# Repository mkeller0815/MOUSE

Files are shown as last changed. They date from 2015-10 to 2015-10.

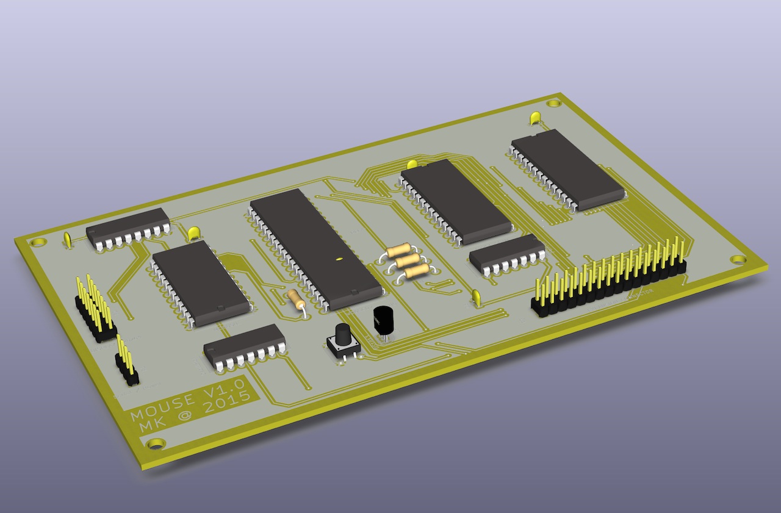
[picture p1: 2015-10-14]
PCB/MOUSE_1-3D.jpg

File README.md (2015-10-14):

# MOUSE

MOUSE (Mario's Own Unique SingleBoard Engine) is minimal 8bit computer system based on the W65C02 microprocessor.

## Files

 * Documentation - documentation, datasheets, images etc.
 * LICENSE - filed under MIT license
 * PCB - KiCad files for pcb of the computer
 * README.md - this file
 * Source - all the sources for the I/O system, minimal OS and some software

Each subdirectory has its own README file with further information about the content

## Concept

This is a single board computer with a minimal chipcount. It is powerd by a USB2Serial Aadapter that also provides 
access to the computer via serial connection. Any TTL serial-adapter that has RX/TX lines as well as +5V and GND 
is suitable.

The computer has 32k SRAM and 8k ROM. There are also 2 extension headers for additional hardware

## Hardware

 * W65C02 CPU 
 * 32k SRAM
 * 8k EEPROM
 * M6850 ACIA (serial interface)
 * DS1813 reset circuit

## Software 

 * DRIVER - provideing highlevel access to peripherals
 * MIOS - Minimal Input/Output System 
 * M-OS - MOUSE OS 
 * Programms - third party software adapted to MOUSE

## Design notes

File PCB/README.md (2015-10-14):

# MOUSE - PCB

This is the pcb sectoion of the project. It provides the schematic as well as the pcb layout and all the files that are needed to create or order a pcb.

## IMPORTANT NOTE

Currently this part is under development and will change in the near future. 

There are two known problems at the moment that make the expension ports less usefull. In the address decoding there are two lines swapped.

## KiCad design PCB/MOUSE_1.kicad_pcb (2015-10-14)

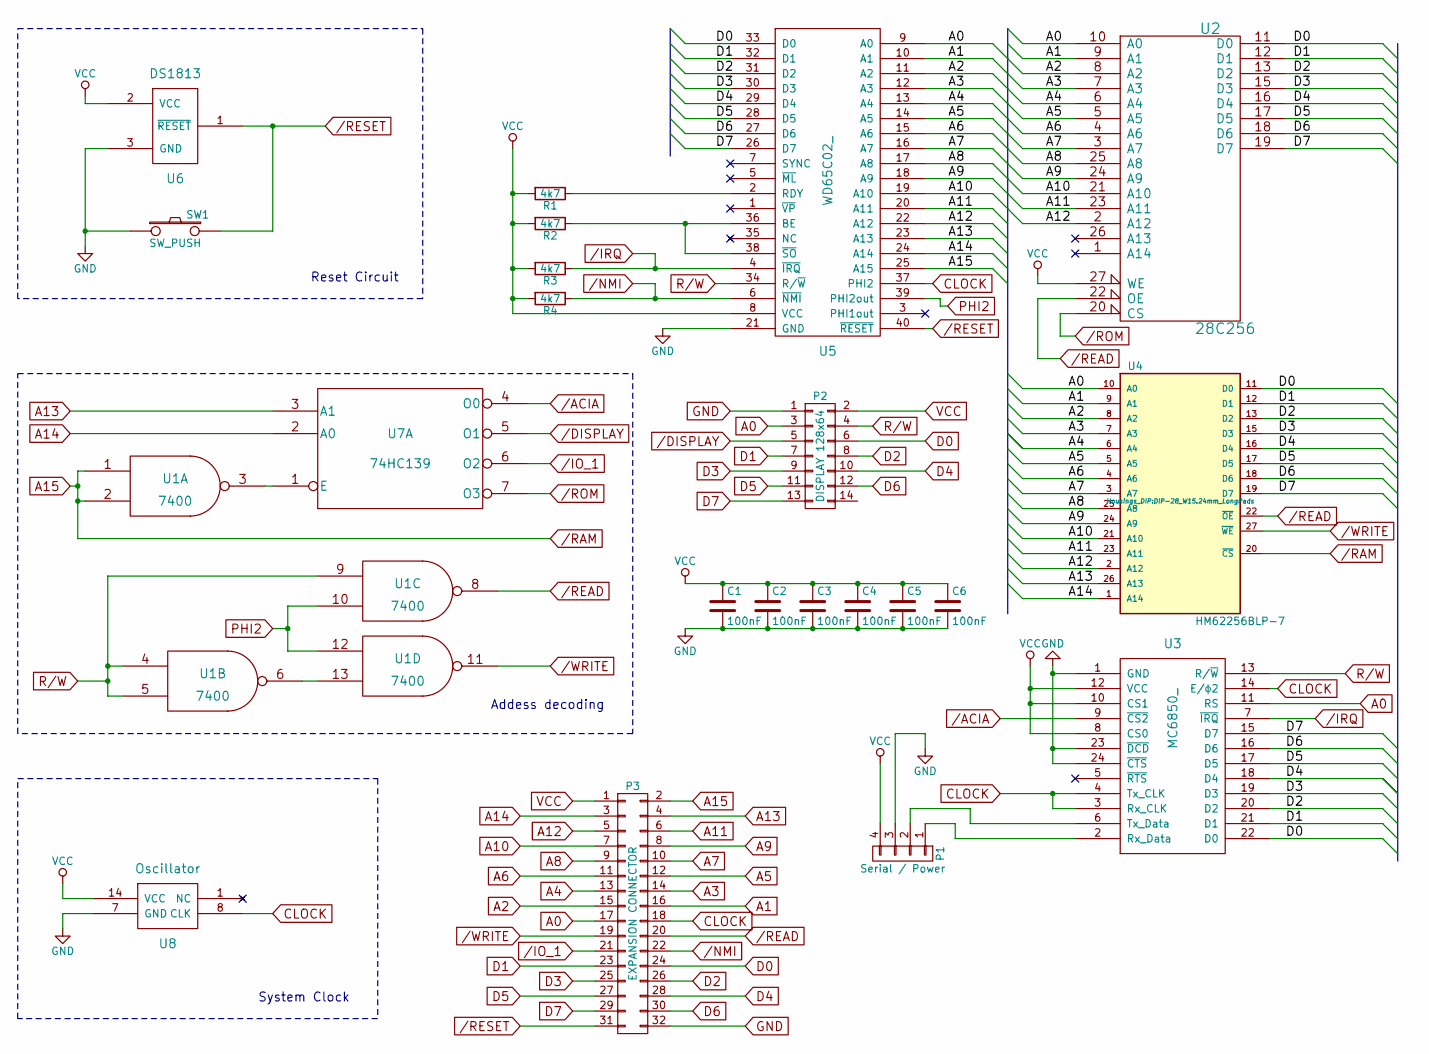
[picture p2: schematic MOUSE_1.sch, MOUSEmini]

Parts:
C1, C2, C3, C4, C5, C6: 100nF; C_Disc_D3_P2.5
P1: Serial / Power; Pin_Header_Straight_1x04
P2: DISPLAY 128x64; Pin_Header_Straight_2x07
P3: EXPANSION CONNECTOR; Pin_Header_Straight_2x16
R1, R2, R3, R4: 4k7; Resistor_Horizontal_RM10mm
SW1: SW_PUSH; SW_PUSH_SMALL
U1: 7400; DIP-14_W7.62mm_LongPads
U2: 28C256; DIP-28_W15.24mm_LongPads
U3: MC6850_; DIP-24_W15.24mm_LongPads
U4: HM62256BLP-7; DIP-28_W15.24mm_LongPads
U5: WD65C02_; DIP-40_W15.24mm_LongPads
U6: DS1813; TO-92_Inline_Narrow_Oval
U7: 74HC139; DIP-16_W7.62mm_LongPads
U8: Oscillator; DIP-14_W7.62mm_LongPads

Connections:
/ACIA: U3.9 (~CS2), U7.4 (O0)
/DISPLAY: P2.5, U7.5 (O1)
/IO_1: P3.21, U7.6 (O2)
/IRQ: R3.1, U3.7 (~IRQ), U5.4 (~IRQ)
/NMI: P3.22, R4.1, U5.6 (~NMI)
/READ: P3.20, U1.8, U2.22 (OE), U4.22 (~OE)
/RESET: P3.31, SW1.2, U5.40 (~RESET), U6.1 (~RESET)
/ROM: U2.20 (CS), U7.7 (O3)
/WRITE: P3.19, U1.11, U4.27 (~WE)
A0: P2.3, P3.17, U2.10 (A0), U3.11 (RS), U4.10 (A0), U5.9 (A0)
A1: P3.16, U2.9 (A1), U4.9 (A1), U5.10 (A1)
A2: P3.15, U2.8 (A2), U4.8 (A2), U5.11 (A2)
A3: P3.14, U2.7 (A3), U4.7 (A3), U5.12 (A3)
A4: P3.13, U2.6 (A4), U4.6 (A4), U5.13 (A4)
A5: P3.12, U2.5 (A5), U4.5 (A5), U5.14 (A5)
A6: P3.11, U2.4 (A6), U4.4 (A6), U5.15 (A6)
A7: P3.10, U2.3 (A7), U4.3 (A7), U5.16 (A7)
A8: P3.9, U2.25 (A8), U4.25 (A8), U5.17 (A8)
A9: P3.8, U2.24 (A9), U4.24 (A9), U5.18 (A9)
A10: P3.7, U2.21 (A10), U4.21 (A10), U5.19 (A10)
A11: P3.6, U2.23 (A11), U4.23 (A11), U5.20 (A11)
A12: P3.5, U2.2 (A12), U4.2 (A12), U5.22 (A12)
A13: P3.4, U4.26 (A13), U5.23 (A13), U7.3 (A1)
A14: P3.3, U4.1 (A14), U5.24 (A14), U7.2 (A0)
A15: P3.2, U1.1, U1.2, U4.20 (~CS), U5.25 (A15)
CLOCK: P3.18, U3.3 (Rx_CLK), U3.4 (Tx_CLK), U3.14 (E/ϕ2), U5.37 (PHI2), U8.8 (CLK)
D0: P2.6, P3.24, U2.11 (D0), U3.22 (D0), U4.11 (D0), U5.33 (D0)
D1: P2.7, P3.23, U2.12 (D1), U3.21 (D1), U4.12 (D1), U5.32 (D1)
D2: P2.8, P3.26, U2.13 (D2), U3.20 (D2), U4.13 (D2), U5.31 (D2)
D3: P2.9, P3.25, U2.15 (D3), U3.19 (D3), U4.15 (D3), U5.30 (D3)
D4: P2.10, P3.28, U2.16 (D4), U3.18 (D4), U4.16 (D4), U5.29 (D4)
D5: P2.11, P3.27, U2.17 (D5), U3.17 (D5), U4.17 (D5), U5.28 (D5)
D6: P2.12, P3.30, U2.18 (D6), U3.16 (D6), U4.18 (D6), U5.27 (D6)
D7: P2.13, P3.29, U2.19 (D7), U3.15 (D7), U4.19 (D7), U5.26 (D7)
GND: C1.2, C2.2, C3.2, C4.2, C5.2, C6.2, P1.3, P2.1, P3.32, SW1.1, U1.7 (GND), U2.14 (GND), U3.1 (GND), U3.23 (~DCD), U3.24 (~CTS), U4.14 (GND), U5.21 (GND), U6.3 (GND), U7.8 (GND), U8.7 (GND)
unnamed: P1.1, U3.2 (Rx_Data)
unnamed: P1.2, U3.6 (Tx_Data)
unnamed: R1.1, U5.2 (RDY)
unnamed: R2.1, U5.36 (BE), U5.38 (~SO)
unnamed: U1.3, U7.1 (E)
unnamed: U1.6, U1.13
PHI2: U1.10, U1.12, U5.39 (PHI2out)
R/W: P2.4, U1.4, U1.5, U1.9, U3.13 (R/~W), U5.34 (R/~W)
VCC: C1.1, C2.1, C3.1, C4.1, C5.1, C6.1, P1.4, P2.2, P3.1, R1.2, R2.2, R3.2, R4.2, U1.14 (VCC), U2.27 (WE), U2.28 (VCC), U3.8 (CS0), U3.10 (CS1), U3.12 (VCC), U4.28 (VCC), U5.8 (VCC), U6.2 (VCC), U7.16 (VCC), U8.14 (VCC)

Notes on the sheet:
Reset Circuit
Addess decoding
System Clock

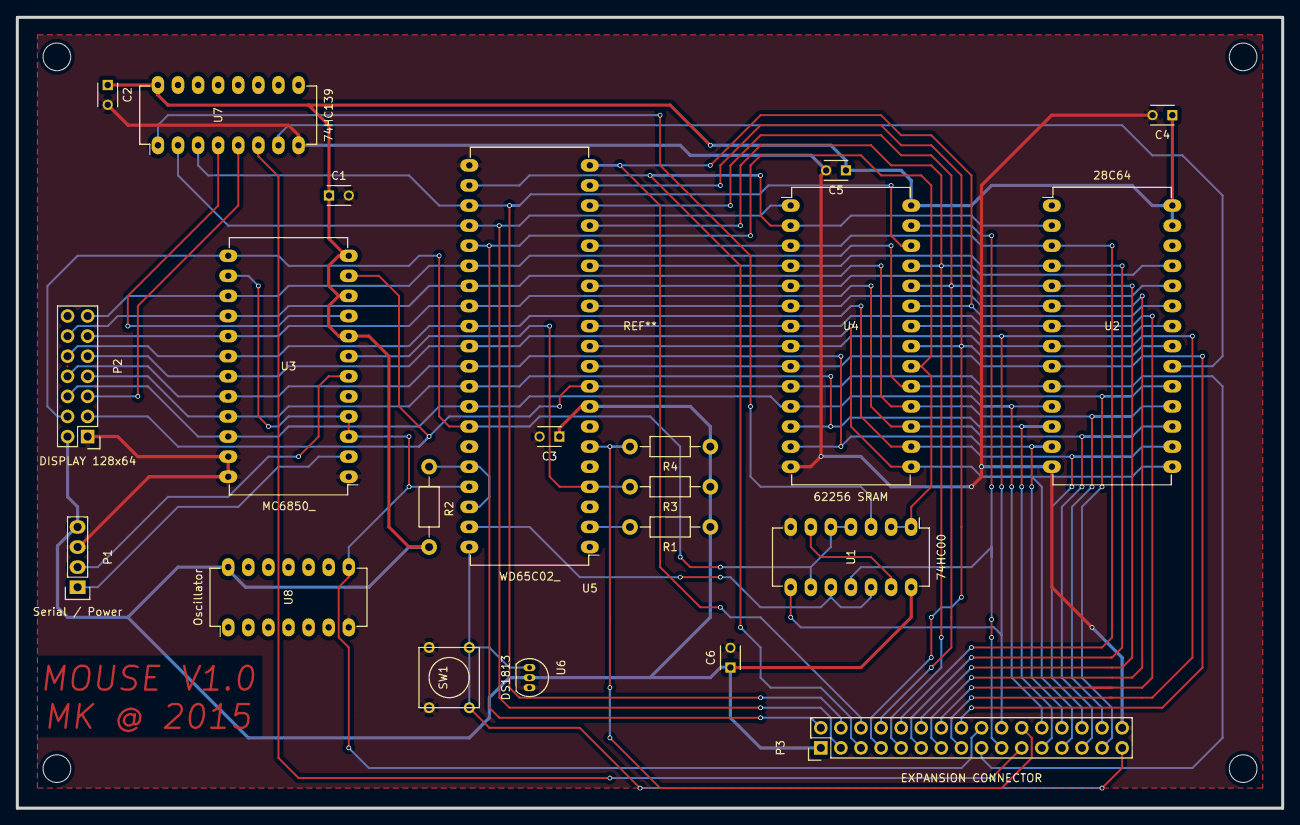
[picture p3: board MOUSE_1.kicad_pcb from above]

Board: 2 copper layers, 160.0 x 100.0 mm, 22 parts (0 on the bottom side), 44 nets.

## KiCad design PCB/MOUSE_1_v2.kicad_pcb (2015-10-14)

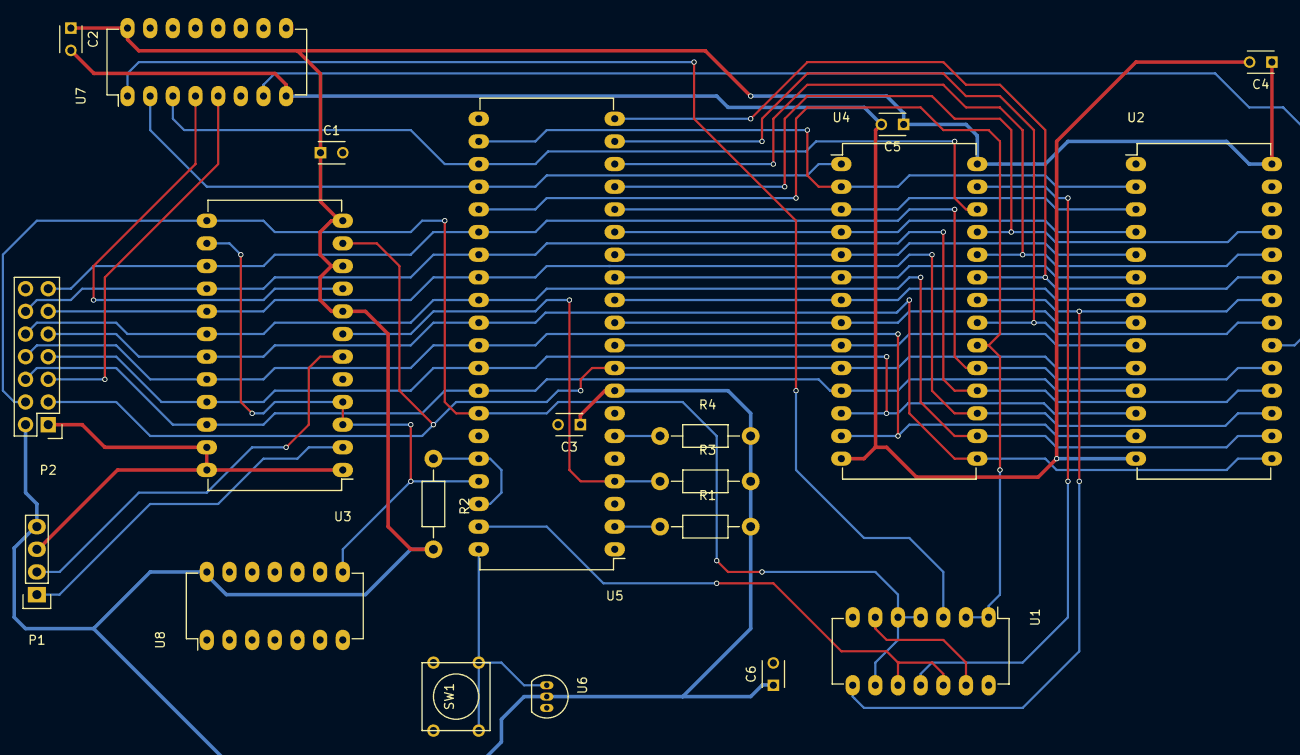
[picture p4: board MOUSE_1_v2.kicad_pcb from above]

Board: 2 copper layers, 21 parts (0 on the bottom side), 43 nets.

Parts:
C1, C2, C3, C4, C5, C6: 100nF; C_Disc_D3_P2.5
P1: Serial / Power; Pin_Header_Straight_1x04
P2: DISPLAY 128x64; Pin_Header_Straight_2x07
R1, R2, R3, R4: 4k7; Resistor_Horizontal_RM10mm
SW1: SW_PUSH; SW_PUSH_SMALL
U1: 7400; DIP-14_W7.62mm_LongPads
U2: 28C256; DIP-28_W15.24mm_LongPads
U3: MC6850_; DIP-24_W15.24mm_LongPads
U4: HM62256BLP-7; DIP-28_W15.24mm_LongPads
U5: WD65C02_; DIP-40_W15.24mm_LongPads
U6: DS1813; TO-92_Inline_Narrow_Oval
U7: 74HC139; DIP-16_W7.62mm_LongPads
U8: Oscillator; DIP-14_W7.62mm_LongPads

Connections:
/A1: U2.9, U4.9, U5.10
/A2: U2.8, U4.8, U5.11
/A3: U2.7, U4.7, U5.12
/A4: U2.6, U4.6, U5.13
/A5: U2.5, U4.5, U5.14
/A6: U2.4, U4.4, U5.15
/A7: U2.3, U4.3, U5.16
/A8: U2.25, U4.25, U5.17
/A9: U2.24, U4.24, U5.18
/A10: U2.21, U4.21, U5.19
/A11: U2.23, U4.23, U5.20
/A12: U2.2, U4.2, U5.22
/ACIA: U3.9, U7.4
/DISPLAY: P2.5, U7.5
/IRQ: R3.1, U3.7, U5.4
/NMI: R4.1, U5.6
/RAM: U1.1, U1.2, U4.20, U5.25
/READ: U1.8, U2.22, U4.22
/RESET: SW1.2, U5.40, U6.1
/ROM: U2.20, U7.7
/WRITE: U1.11, U4.27
A0: P2.3, U2.10, U3.11, U4.10, U5.9
A13: U4.26, U5.23, U7.3
A14: U4.1, U5.24, U7.2
CLOCK: U3.3, U3.4, U3.14, U5.37, U8.8
D0: P2.6, U2.11, U3.22, U4.11, U5.33
D1: P2.7, U2.12, U3.21, U4.12, U5.32
D2: P2.8, U2.13, U3.20, U4.13, U5.31
D3: P2.9, U2.15, U3.19, U4.15, U5.30
D4: P2.10, U2.16, U3.18, U4.16, U5.29
D5: P2.11, U2.17, U3.17, U4.17, U5.28
D6: P2.12, U2.18, U3.16, U4.18, U5.27
D7: P2.13, U2.19, U3.15, U4.19, U5.26
GND: C1.2, C2.2, C3.2, C4.2, C5.2, C6.2, P1.3, P2.1, SW1.1, U1.7, U2.14, U3.1, U3.23, U3.24, U4.14, U5.21, U6.3, U7.8, U8.7
unnamed: P1.1, U3.2
unnamed: P1.2, U3.6
unnamed: R1.1, U5.2
unnamed: R2.1, U5.36, U5.38
unnamed: U1.3, U7.1
unnamed: U1.6, U1.13
PHI2: U1.10, U1.12, U5.39
R/W: P2.4, U1.4, U1.5, U1.9, U3.13, U5.34
VCC: C1.1, C2.1, C3.1, C4.1, C5.1, C6.1, P1.4, P2.2, R1.2, R2.2, R3.2, R4.2, U1.14, U2.27, U2.28, U3.8, U3.10, U3.12, U4.28, U5.8, U6.2, U7.16, U8.14

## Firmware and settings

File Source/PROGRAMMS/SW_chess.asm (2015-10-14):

;***********************************************************************
;
;  Kim-1 MicroChess (c) 1976-2005 Peter Jennings, www.benlo.com
;
;***********************************************************************

; All rights reserved.

; Redistribution and use in source and binary forms, with or without
; modification, are permitted provided that the following conditions
; are met:
; 1. Redistributions of source code must retain the above copyright
;    notice, this list of conditions and the following disclaimer.
; 2. Redistributions in binary form must reproduce the above copyright
;    notice, this list of conditions and the following disclaimer in the
;    documentation and/or other materials provided with the distribution.
; 3. The name of the author may not be used to endorse or promote products
;    derived from this software without specific prior written permission.

; THIS SOFTWARE IS PROVIDED BY THE AUTHOR ''AS IS'' AND ANY EXPRESS OR
; IMPLIED WARRANTIES, INCLUDING, BUT NOT LIMITED TO, THE IMPLIED WARRANTIES
; OF MERCHANTABILITY AND FITNESS FOR A PARTICULAR PURPOSE ARE DISCLAIMED.
; IN NO EVENT SHALL THE AUTHOR BE LIABLE FOR ANY DIRECT, INDIRECT,
; INCIDENTAL, SPECIAL, EXEMPLARY, OR CONSEQUENTIAL DAMAGES (INCLUDING, BUT
; NOT LIMITED TO, PROCUREMENT OF SUBSTITUTE GOODS OR SERVICES; LOSS OF USE,
; DATA, OR PROFITS; OR BUSINESS INTERRUPTION) HOWEVER CAUSED AND ON ANY
; THEORY OF LIABILITY, WHETHER IN CONTRACT, STRICT LIABILITY, OR TORT
; (INCLUDING NEGLIGENCE OR OTHERWISE) ARISING IN ANY WAY OUT OF THE USE OF
; THIS SOFTWARE, EVEN IF ADVISED OF THE POSSIBILITY OF SUCH DAMAGE.

;
; modified by Daryl Rictor to work over a
; serial terminal connection, August 2002.
;
; Updated with corrections to earlier OCR errors by Bill Forster, August 2005.
;
; Adapted by Mario Keller for MOUSE I/O, September 2015
;
; publishing this source code was granted by Peter Jennings Oct 2015, but the
; copyright has still to be respected in all terms.
;
.alias BOARD   	$50 
.alias BK      	$60 
.alias PIECE   	$B0 
.alias SQUARE  	$B1 
.alias SP2     	$B2 
.alias SP1     	$B3 
.alias INCHEK  	$B4 
.alias STATE   	$B5 
.alias MOVEN   	$B6 
.alias REV	$B7
.alias OMOVE   	$DC 
.alias WCAP0   	$DD 
.alias COUNT   	$DE 
.alias BCAP2   	$DE 
.alias WCAP2   	$DF 
.alias BCAP1   	$E0 
.alias WCAP1   	$E1 
.alias BCAP0   	$E2 
.alias MOB     	$E3 
.alias MAXC    	$E4 
.alias CC      	$E5 
.alias PCAP    	$E6 
.alias BMOB    	$E3 
.alias BMAXC   	$E4 
.alias BMCC    	$E5 		; was BCC (TASS doesn't like it as a label)
.alias BMAXP   	$E6 
.alias XMAXC   	$E8 
.alias WMOB    	$EB 
.alias WMAXC   	$EC 
.alias WCC     	$ED 
.alias WMAXP   	$EE 
.alias PMOB    	$EF 
.alias PMAXC   	$F0 
.alias PCC     	$F1 
.alias PCP     	$F2 
.alias OLDKY   	$F3 
.alias BESTP   	$FB 
.alias BESTV   	$FA 
.alias BESTM   	$F9 
.alias DIS1    	$FB 
.alias DIS2    	$FA 
.alias DIS3    	$F9 
.alias temp	$FC
;
;NOTE THAT $B7 TO $BF, $F4 TO $F8, AND $FC TO $FF ARE
;AVAILABLE FOR USER EXPANSION AND I/O ROUTINES
;
;		*=$1000			; load into RAM @ $1000-$15FF

		LDA     #$00		; REVERSE TOGGLE
		STA     REV
CHESS:		CLD			; INITIALIZE
		LDX	#$FF		; TWO STACKS
		TXS	
		LDX	#$C8
		STX	SP2
;		
;       ROUTINES TO LIGHT LED
;       DISPLAY AND GET KEY
;       FROM KEYBOARD
;		
OUT:		JSR	pout		; DISPLAY AND
		JSR	KIN		; GET INPUT   *** my routine waits for a keypress
;		CMP	OLDKY		; KEY IN ACC  *** no need to debounce
;		BEQ	OUT		; (DEBOUNCE)
;		STA	OLDKY
;		
		CMP	#$43		; [C]
		BNE	NOSET		; SET UP
		LDX	#$1F		; BOARD
WHSET:		LDA	SETW,X		; FROM
		STA	BOARD,X		; SETW
		DEX	
		BPL	WHSET
		LDX	#$1B		; *ADDED
		STX	OMOVE		; INITS TO $FF
		LDA	#$CC		; Display CCC
		BNE	CLDSP
;		
NOSET:		CMP	#$45		; [E]
		BNE	NOREV		; REVERSE
		JSR	REVERSE        	; BOARD IS
		SEC
		LDA	#$01
		SBC	REV
		STA	REV		; TOGGLE REV FLAG
		LDA	#$EE            ; IS
		BNE	CLDSP
;		
NOREV:		CMP	#$40			; [P]
		BNE	NOGO           	; PLAY CHESS
		JSR	GO
CLDSP:		STA	DIS1          	; DISPLAY
		STA	DIS2         	; ACROSS
		STA	DIS3          	; DISPLAY
		BNE	CHESS
;		
NOGO:		CMP	#$0D            ; [Enter]
		BNE	NOMV          	; MOVE MAN
		JSR	MOVEXX          	; AS ENTERED
		JMP	DISP
NOMV:		CMP     #$41		; [Q] ***Added to allow game exit***
		BEQ     DONE		; quit the game
		JMP	INPUT		; process move
DONE:		JMP     MOUSESTART	; exit back to SBC's Monitor
;		
;       THE ROUTINE JANUS DIRECTS THE
;       ANALYSIS BY DETERMINING WHAT
;       SHOULD OCCUR AFTER EACH MOVE
;       GENERATED BY GNM
;		
;		
;
JANUS:		LDX	STATE
		BMI	NOCOUNT
;		
;       THIS ROUTINE COUNTS OCCURRENCES
;       IT DEPENDS UPON STATE TO INDEX
;       THE CORRECT COUNTERS
;		
COUNTS:		LDA	PIECE
		BEQ	OVER           	; IF STATE=8
		CPX 	#$08           	; DO NOT COUNT
		BNE	OVER          	; BLK MAX CAP
		CMP	BMAXP        	; MOVES FOR
		BEQ	XRT           	; WHITE
; 		
OVER:		INC	MOB,X          	; MOBILITY
		CMP 	#$01           	;  + QUEEN
		BNE	NOQ           	; FOR TWO
		INC	MOB,X
;		
NOQ:		BVC	NOCAP
		LDY	#$0F           	; CALCULATE
		LDA	SQUARE       	; POINTS
ELOOOP:		CMP	BK,Y           	; CAPTURED
		BEQ	FOUN          	; BY THIS
		DEY			; MOVE
		BPL	ELOOOP
FOUN:		LDA	POINTS,Y
		CMP	MAXC,X
		BCC	LESS          	; SAVE IF
		STY	PCAP,X         	; BEST THIS
		STA	MAXC,X         	; STATE
;		
LESS:		CLC	
		PHP			; ADD TO
		ADC	CC,X           	; CAPTURE
		STA	CC,X           	; COUNTS
		PLP	
;		
NOCAP:		CPX	#$04
		BEQ	ON4
		BMI	TREE          	;(=00 ONLY)
XRT:		RTS	
;		
;      GENERATE FURTHER MOVES FOR COUNT
;      AND ANALYSIS	
;		
ON4:		LDA	XMAXC        	; SAVE ACTUAL 
		STA	WCAP0         	; CAPTURE
		LDA	#$00           	; STATE=0
		STA	STATE
		JSR	MOVEXX          	; GENERATE
		JSR	REVERSE       	; IMMEDIATE
		JSR	GNMZ         	; REPLY MOVES  
		JSR	REVERSE
;		
		LDA	#$08       	; STATE=8
		STA	STATE        	; GENERATE
;		JSR	OHM          	; CONTINUATION
		JSR	UMOVE         	; MOVES
;		
		JMP	STRATGY       	; FINAL EVALUATION
NOCOUNT:	CPX	#$F9
		BNE	TREE
;		
;      DETERMINE IF THE KING CAN BE
;      TAKEN, USED BY CHKCHK
;		
		LDA	BK           	; IS KING
		CMP	SQUARE       	; IN CHECK?
		BNE	RETJ          	; SET INCHEK=0
		LDA	#$00           	; IF IT IS
		STA	INCHEK
RETJ:		RTS	
;		
;      IF A PIECE HAS BEEN CAPTURED BY
;      A TRIAL MOVE, GENERATE REPLIES &
;      EVALUATE THE EXCHANGE GAIN/LOSS
;		
TREE:		BVC	RETJ          	; NO CAP
		LDY	#$07           	; (PIECES)
		LDA	SQUARE
LOOPX:		CMP	BK,Y
		BEQ	FOUNX
		DEY	
		BEQ	RETJ          	; (KING)
		BPL	LOOPX         	; SAVE
FOUNX:		LDA	POINTS,Y       	; BEST CAP
		CMP	BCAP0,X        	; AT THIS
		BCC	NOMAX         	; LEVEL
		STA	BCAP0,X
NOMAX:		DEC	STATE
		LDA	#$FB           	; IF STATE=FB
		CMP	STATE        	; TIME TO TURN
		BEQ	UPTREE        	; AROUND
		JSR	GENRM         	; GENERATE FURTHER
UPTREE:		INC	STATE        	; CAPTURES
		RTS	
;		
;      THE PLAYER'S MOVE IS INPUT
;		
INPUT:		CMP	#$08           	; NOT A LEGAL
		BCS	ERROR      	; SQUARE #
		JSR	DISMV
DISP:		LDX	#$1F
SEARCH:		LDA	BOARD,X
		CMP	DIS2
		BEQ	HERE          	; DISPLAY
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

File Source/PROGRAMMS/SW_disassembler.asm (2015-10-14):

;
; 6502/65C02 Disassembler
;
; Copyright (C) 2012 by Jeff Tranter <tranter@pobox.com>
;
; Licensed under the Apache License, Version 2.0 (the "License");
; you may not use this file except in compliance with the License.
; You may obtain a copy of the License at
;
;   http://www.apache.org/licenses/LICENSE-2.0
;
; Unless required by applicable law or agreed to in writing, software
; distributed under the License is distributed on an "AS IS" BASIS,
; WITHOUT WARRANTIES OR CONDITIONS OF ANY KIND, either express or implied.
; See the License for the specific language governing permissions and
; limitations under the License.
;
; Revision History
; Version Date         Comments
; 0.0     25-Mar-2012  First version started
; 0.9     28-Mar-2012  First public beta version

; *** ASSEMBLY TIME OPTIONS ***

; Uncomment this if you don't want instructions that operate on the
; accumulator like ASL to be shown as "ASL A" but instead just "ASL".
; NOACCUMULATOR = 1

; Uncomment this if you want the output to include source code only
; and not the data bytes in memory. This allows the output to be fed
; back to an assembler.
; SOURCEONLY = 1
        
; Uncomment next line to link with start address of $A000 for Multi I/0 Board EEPROM.
; .org $A000

; *** CONSTANTS ***

; Characters
.alias  CR     $0D ; Carriage Return
.alias  SP     $20 ; Space
.alias  ESC    $1B ; Escape

; External Routines
;.alias  ECHO        $FFEF ; Woz monitor ECHO routine
;.alias  PRBYTE      $FFDC ; Woz monitor print byte as two hex chars
;.alias  PRHEX       $FFE5 ; Woz monitor print nybble as hex digit

; Instructions. Matches entries in table of MNEMONICS
.alias OP_INV    $00
.alias OP_ADC    $01
.alias OP_AND    $02
.alias OP_ASL    $03
.alias OP_BCC    $04
.alias OP_BCS    $05
.alias OP_BEQ    $06
.alias OP_BIT    $07
.alias OP_BMI    $08
.alias OP_BNE    $09
.alias OP_BPL    $0A
.alias OP_BRK    $0B
.alias OP_BVC    $0C
.alias OP_BVS    $0D
.alias OP_CLC    $0E
.alias OP_CLD    $0F
.alias OP_CLI    $10
.alias OP_CLV    $11
.alias OP_CMP    $12
.alias OP_CPX    $13
.alias OP_CPY    $14
.alias OP_DEC    $15
.alias OP_DEX    $16
.alias OP_DEY    $17
.alias OP_EOR    $18
.alias OP_INC    $19
.alias OP_INX    $1A
.alias OP_INY    $1B
.alias OP_JMP    $1C
.alias OP_JSR    $1D
.alias OP_LDA    $1E
.alias OP_LDX    $1F
.alias OP_LDY    $20
.alias OP_LSR    $21
.alias OP_NOP    $22
.alias OP_ORA    $23
.alias OP_PHA    $24
.alias OP_PHP    $25
.alias OP_PLA    $26
.alias OP_PLP    $27
.alias OP_ROL    $28
.alias OP_ROR    $29
.alias OP_RTI    $2A
.alias OP_RTS    $2B
.alias OP_SBC    $2C
.alias OP_SEC    $2D
.alias OP_SED    $2E
.alias OP_SEI    $2F
.alias OP_STA    $30
.alias OP_STX    $31
.alias OP_STY    $32
.alias OP_TAX    $33
.alias OP_TAY    $34
.alias OP_TSX    $35
.alias OP_TXA    $36
.alias OP_TXS    $37
.alias OP_TYA    $38
.alias OP_BBR    $39 ; [65C02 only]
.alias OP_BBS    $3A ; [65C02 only]
.alias OP_BRA    $3B ; [65C02 only]
.alias OP_PHX    $3C ; [65C02 only]
.alias OP_PHY    $3D ; [65C02 only]
.alias OP_PLX    $3E ; [65C02 only]
.alias OP_PLY    $3F ; [65C02 only]
.alias OP_RMB    $40 ; [65C02 only]
.alias OP_SMB    $41 ; [65C02 only]
.alias OP_STZ    $42 ; [65C02 only]
.alias OP_TRB    $43 ; [65C02 only]
.alias OP_TSB    $44 ; [65C02 only]
.alias OP_STP    $45 ; [WDC 65C02 only]
.alias OP_WAI    $46 ; [WDC 65C02 only]

; Addressing Modes. OPCODES1/OPCODES2 tables list these for each instruction. LENGTHS lists the instruction length for each addressing mode.
.alias AM_INVALID    0                    ; example:
.alias AM_IMPLICIT    1                   ; RTS
.alias AM_ACCUMULATOR    2                ; ASL A
.alias AM_IMMEDIATE    3                  ; LDA #$12
.alias AM_ZEROPAGE    4                   ; LDA $12
.alias AM_ZEROPAGE_X    5                 ; LDA $12,X
.alias AM_ZEROPAGE_Y    6                 ; LDA $12,Y
.alias AM_RELATIVE    7                   ; BNE $FD
.alias AM_ABSOLUTE    8                   ; JSR $1234
.alias AM_ABSOLUTE_X    9                 ; STA $1234,X
.alias AM_ABSOLUTE_Y    10                ; STA $1234,Y
.alias AM_INDIRECT    11                  ; JMP ($1234)
.alias AM_INDEXED_INDIRECT    12          ; LDA ($12,X)
.alias AM_INDIRECT_INDEXED    13          ; LDA ($12),Y
.alias AM_INDIRECT_ZEROPAGE    14         ; LDA ($12) [65C02 only]
.alias AM_ABSOLUTE_INDEXED_INDIRECT    15 ; JMP ($1234,X) [65C02 only]

; *** VARIABLES ***

; Page zero variables
.alias T1        $35     ; temp variable 1
.alias T2        $36     ; temp variable 2
;.alias ADDR      $37     ; instruction address, 2 bytes (low/high)
.alias OPCODE    $39     ; instruction opcode
.alias OP        $3A     ; instruction type OP_*
.alias AM        $41     ; addressing mode AM_*
.alias LEN       $42     ; instruction length
.alias REL       $43     ; relative addressing branch offset (2 bytes)
.alias DEST      $45     ; relative address destination address (2 bytes)

; *** CODE ***

; Main program disassembles starting from itself. Prompts user to hit
; key to continue after each screen.
DSTART:
OUTER:
.invoke linefeed
  LDA #23
DLOOP:
  PHA
  JSR DISASM
  PLA
  SEC
  SBC #1
  BNE DLOOP
.invoke print ContinueString
SpaceOrEscape:
  JSR j_rchr
  CMP #$20
  BEQ OUTER
  CMP #$1B
  BNE SpaceOrEscape
  JMP m_parse_end
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
